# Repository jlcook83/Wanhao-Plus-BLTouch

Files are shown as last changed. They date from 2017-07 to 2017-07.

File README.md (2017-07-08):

# Wanhao-Plus-BLTouch
Wanhao i3 PLUS / Monoprice Maker Select PLUS - Marlin 1.1.3 Configured for BLTouch bed levelling probe and fully functional touch screen. 

This port is of Marlin v 1.1.3 pre-configured for use of BLTouch for bed levelling on the Wanhao i3 PLUS (with touch display) and it's various clones such as the Monoprice Maker Select Plus.

This firmware is only confirmed to provide full display functionality with the PLUS versions with touchscreen. Some configuration changes may be needed to function with previous versions that have the lcd and wheel.

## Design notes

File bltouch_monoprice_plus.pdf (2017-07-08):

## Installation of BLTouch bed levelling probe

## for

## Wanhao i3 PLUS / Monoprice Maker Select PLUS

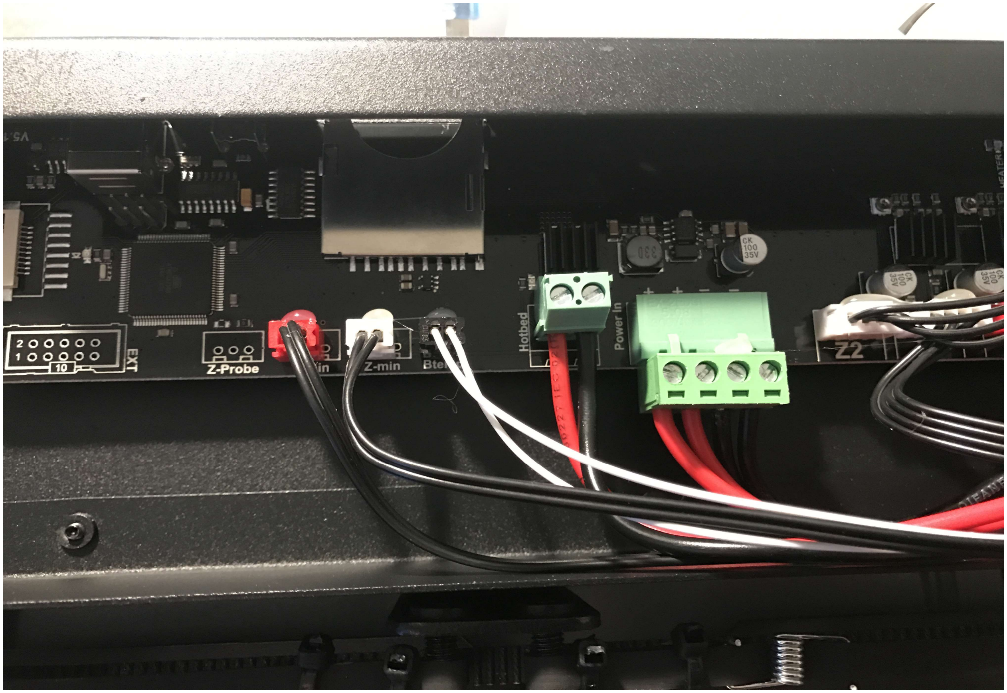
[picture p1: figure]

## 1. Disconnect Z-min connector (white)

* Z-min switch should also be lowered or removed as it will be completely replaced with the BLTouch.

2. Remove ‘0’ ohm jumper from ‘right’ solder pad, then solder jumper onto ‘left’ solder pad.
*This will supply pin 1 of Z-probe connector with 5VDC instead of 24VDC. Picture shown with jumper already moved...

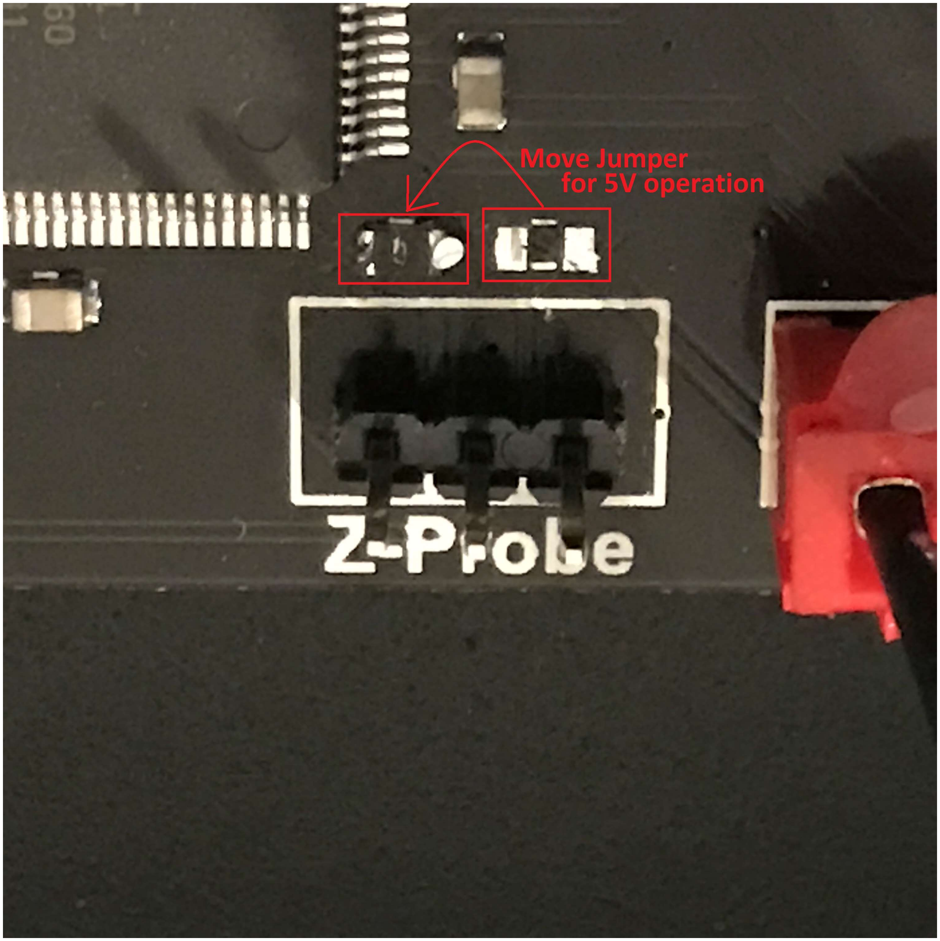
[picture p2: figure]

## 3. Wire BLTouch according to the image below –

> Note the BLTouch wire order is NOT the same as the 3-pin connector on the board, the Red and Orange wires swap positions…. > Black wire from BLTouch does not need to be connected as ground is common to the z-min and z-probe connectors...

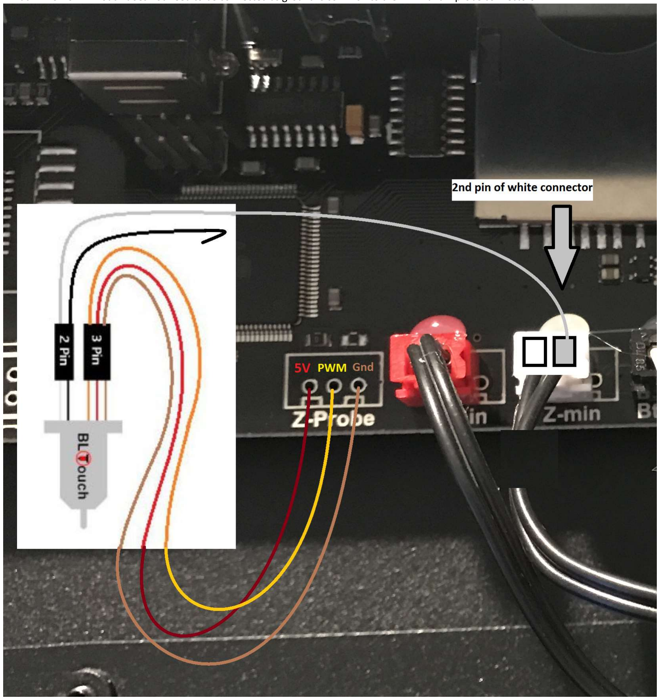
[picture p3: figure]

### 4. Mount BLTouch with an appropriate bracket…

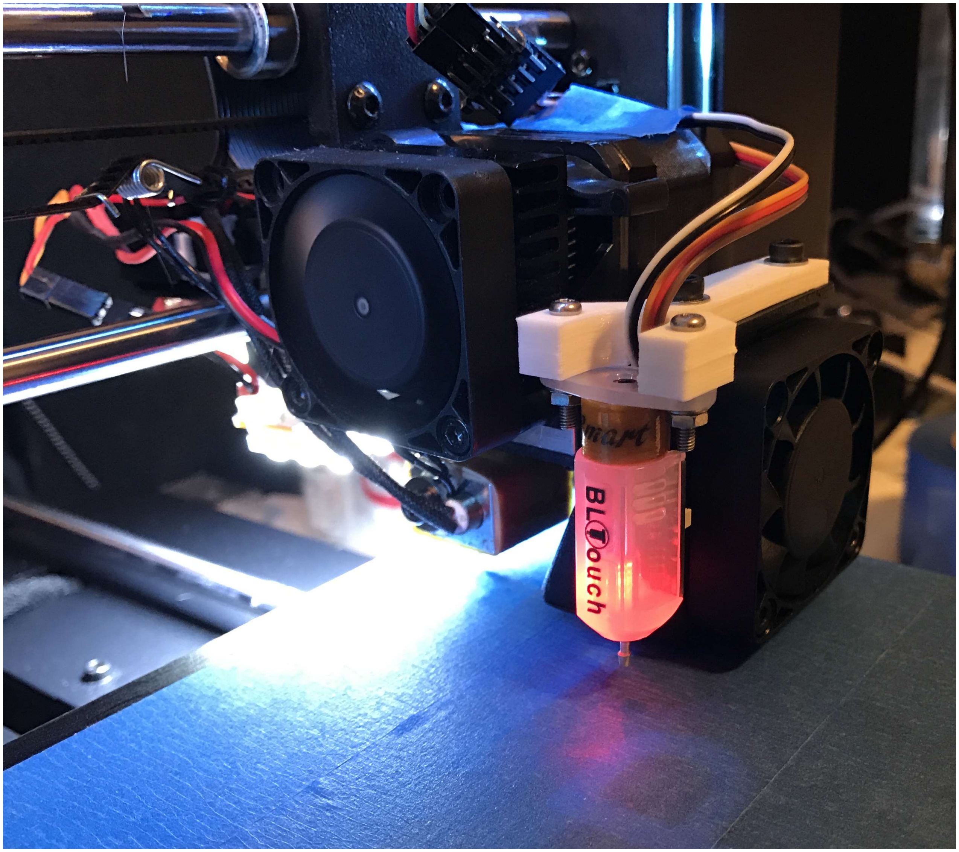
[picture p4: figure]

### 5. Install and configure firmware

- PWM Pin is ‘Arduino’ Pin #25
- Marlin software 1.1 and up has BLTouch as a bed levelling option under ‘configuration.h’

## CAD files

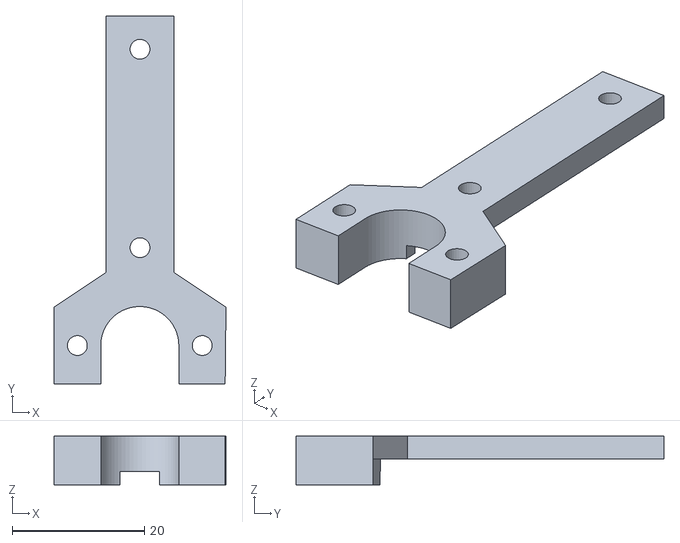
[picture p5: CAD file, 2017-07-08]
BLTouchMountV2.1_bigger.stl
26.0 x 55.6 x 7.40

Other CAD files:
BLTouch.skp

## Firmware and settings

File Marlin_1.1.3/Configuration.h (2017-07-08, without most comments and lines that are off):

#define CONFIGURATION_H
#define CONFIGURATION_H_VERSION 010100
#define STRING_CONFIG_H_AUTHOR "(none, default config)" // Who made the changes.
#define SHOW_BOOTSCREEN
#define STRING_SPLASH_LINE1 SHORT_BUILD_VERSION // will be shown during bootup in line 1
#define STRING_SPLASH_LINE2 WEBSITE_URL         // will be shown during bootup in line 2
#define SERIAL_PORT 0
#define BAUDRATE 115200
  #define MOTHERBOARD BOARD_RAMPS_13_EFB   // CLOSEST MATCH TO Monoprice Maker Select Plus - some modifications in pins_RAMPS.h
#define EXTRUDERS 1
#define POWER_SUPPLY 0  // WAS SET TO ATX '1' in old MMSP FW, but did not have the option '0' before, which is more suited for MMSP
#define TEMP_SENSOR_0 1
#define TEMP_SENSOR_1 0
#define TEMP_SENSOR_2 0
#define TEMP_SENSOR_3 0
#define TEMP_SENSOR_4 0
#define TEMP_SENSOR_BED 1 //0 ->1 MMSP
#define DUMMY_THERMISTOR_998_VALUE 25
#define DUMMY_THERMISTOR_999_VALUE 100
#define MAX_REDUNDANT_TEMP_SENSOR_DIFF 10
#define TEMP_RESIDENCY_TIME 10  // (seconds)
#define TEMP_HYSTERESIS 3       // (degC) range of +/- temperatures considered "close" to the target one
#define TEMP_WINDOW     1       // (degC) Window around target to start the residency timer x degC early.
#define TEMP_BED_RESIDENCY_TIME 10  // (seconds)
#define TEMP_BED_HYSTERESIS 3       // (degC) range of +/- temperatures considered "close" to the target one
#define TEMP_BED_WINDOW     1       // (degC) Window around target to start the residency timer x degC early.
#define HEATER_0_MINTEMP 0 //5  ->0 MMSP
#define HEATER_1_MINTEMP 5
#define HEATER_2_MINTEMP 5
#define HEATER_3_MINTEMP 5
#define HEATER_4_MINTEMP 5
#define BED_MINTEMP 0 //5  ->0 MMSP
#define HEATER_0_MAXTEMP 260 //275  ->260 MMSP
#define HEATER_1_MAXTEMP 275
#define HEATER_2_MAXTEMP 275
#define HEATER_3_MAXTEMP 275
#define HEATER_4_MAXTEMP 275
#define BED_MAXTEMP 110 //150  ->110 MMSP
#define PIDTEMP
#define BANG_MAX 255 // limits current to nozzle while in bang-bang mode; 255=full current
#define PID_MAX BANG_MAX // limits current to nozzle while PID is active (see PID_FUNCTIONAL_RANGE below); 255=full current
  #define PID_FUNCTIONAL_RANGE 10 // If the temperature difference between the target temperature and the actual temperature
  #define K1 0.95 //smoothing factor within the PID
  #define  DEFAULT_Kp 25.5 //22.2
  #define  DEFAULT_Ki 1.45 //1.08
  #define  DEFAULT_Kd 112  //114
#define MAX_BED_POWER 255 // limits duty cycle to bed; 255=full current
#define PREVENT_COLD_EXTRUSION
#define EXTRUDE_MINTEMP 170
#define PREVENT_LENGTHY_EXTRUDE
#define EXTRUDE_MAXLENGTH (X_MAX_LENGTH+Y_MAX_LENGTH) //200  ->(X_MAX_LENGTH+Y_MAX_LENGTH) FROM OLD FW
#define THERMAL_PROTECTION_HOTENDS // Enable thermal protection for all extruders
#define THERMAL_PROTECTION_BED     // Enable thermal protection for the heated bed
#define USE_XMIN_PLUG
#define USE_YMIN_PLUG
#define USE_ZMIN_PLUG
  #define ENDSTOPPULLUP_XMIN  // USED FOR X SWITCH ON MMSP
  #define ENDSTOPPULLUP_YMIN  // USED FOR Y SWITCH ON MMSP
#define X_MIN_ENDSTOP_INVERTING true //false // set to true to invert the logic of the endstop.
#define Y_MIN_ENDSTOP_INVERTING true //false // set to true to invert the logic of the endstop.
#define Z_MIN_ENDSTOP_INVERTING false // set to true to invert the logic of the endstop.
#define X_MAX_ENDSTOP_INVERTING false // set to true to invert the logic of the endstop.
#define Y_MAX_ENDSTOP_INVERTING false // set to true to invert the logic of the endstop.
#define Z_MAX_ENDSTOP_INVERTING false // set to true to invert the logic of the endstop.
#define Z_MIN_PROBE_ENDSTOP_INVERTING false // set to true to invert the logic of the probe.
#define DEFAULT_AXIS_STEPS_PER_UNIT   { 80, 80, 400, 99 }
#define DEFAULT_MAX_FEEDRATE          { 450, 450, 5, 25 }  //{ 300, 300, 5, 25 } //MMSP
#define DEFAULT_MAX_ACCELERATION      { 3000, 3000, 100, 3000 } // {400,400,100,3000}  //MMSP
#define DEFAULT_ACCELERATION          800 //3000    // X, Y, Z and E acceleration for printing moves
#define DEFAULT_RETRACT_ACCELERATION  800 //3000    // E acceleration for retracts
#define DEFAULT_TRAVEL_ACCELERATION   800 //3000    // X, Y, Z acceleration for travel (non printing) moves
#define DEFAULT_XJERK                 10.0 //20.0
#define DEFAULT_YJERK                 10.0 //20.0
#define DEFAULT_ZJERK                 0.4
#define DEFAULT_EJERK                 1.0 // 5.0
#define Z_MIN_PROBE_USES_Z_MIN_ENDSTOP_PIN
#define BLTOUCH
  #define BLTOUCH_DELAY 375   // (ms) Enable and increase if needed
#define X_PROBE_OFFSET_FROM_EXTRUDER -21 //10  // X offset: -left  +right  [of the nozzle]
#define Y_PROBE_OFFSET_FROM_EXTRUDER -46 //10  // Y offset: -front +behind [the nozzle]
#define Z_PROBE_OFFSET_FROM_EXTRUDER -1.5 //0   // Z offset: -below +above  [the nozzle]
#define XY_PROBE_SPEED 8000
#define Z_PROBE_SPEED_FAST (HOMING_FEEDRATE_Z)
#define Z_PROBE_SPEED_SLOW (Z_PROBE_SPEED_FAST / 3.0)
#define PROBE_DOUBLE_TOUCH
#define Z_CLEARANCE_DEPLOY_PROBE   3// Z Clearance for Deploy/Stow
#define Z_CLEARANCE_BETWEEN_PROBES  5 // Z Clearance between probe points
#define Z_PROBE_OFFSET_RANGE_MIN -20
#define Z_PROBE_OFFSET_RANGE_MAX 20
#define Z_MIN_PROBE_REPEATABILITY_TEST
#define X_ENABLE_ON 0
#define Y_ENABLE_ON 0
#define Z_ENABLE_ON 0
#define E_ENABLE_ON 0 // For all extruders
#define DISABLE_X false
#define DISABLE_Y false
#define DISABLE_Z false
#define DISABLE_E false // For all extruders
#define DISABLE_INACTIVE_EXTRUDER true // Keep only the active extruder enabled.
#define INVERT_X_DIR true //false
#define INVERT_Y_DIR true
#define INVERT_Z_DIR false
#define INVERT_E0_DIR false
#define INVERT_E1_DIR false
#define INVERT_E2_DIR false
#define INVERT_E3_DIR false
#define INVERT_E4_DIR false
#define Z_HOMING_HEIGHT 5  // (in mm) Minimal z height before homing (G28) for Z clearance above the bed, clamps, ...
#define X_HOME_DIR -1
#define Y_HOME_DIR -1
#define Z_HOME_DIR -1
#define X_MIN_POS 0
#define Y_MIN_POS 0
#define Z_MIN_POS 0
#define X_MAX_POS 200
#define Y_MAX_POS 206
#define Z_MAX_POS 180
#define MIN_SOFTWARE_ENDSTOPS
#define MAX_SOFTWARE_ENDSTOPS
#define AUTO_BED_LEVELING_BILINEAR
  #define ENABLE_LEVELING_FADE_HEIGHT
  #define GRID_MAX_POINTS_X 3
  #define GRID_MAX_POINTS_Y GRID_MAX_POINTS_X
  #define LEFT_PROBE_BED_POSITION 20
  #define RIGHT_PROBE_BED_POSITION 169
  #define FRONT_PROBE_BED_POSITION 20
  #define BACK_PROBE_BED_POSITION 160
  #define MIN_PROBE_EDGE 10
#define Z_SAFE_HOMING
  #define Z_SAFE_HOMING_X_POINT ((X_MIN_POS + X_MAX_POS) / 2)    // X point for Z homing when homing all axis (G28).
  #define Z_SAFE_HOMING_Y_POINT ((Y_MIN_POS + Y_MAX_POS) / 2)    // Y point for Z homing when homing all axis (G28).
#define HOMING_FEEDRATE_XY (50*60)
#define HOMING_FEEDRATE_Z  (4*60)
#define EEPROM_SETTINGS
  #define EEPROM_CHITCHAT // Please keep turned on if you can.
#define HOST_KEEPALIVE_FEATURE        // Disable this if your host doesn't like keepalive messages
#define DEFAULT_KEEPALIVE_INTERVAL 2  // Number of seconds between "busy" messages. Set with M113.
#define PREHEAT_1_TEMP_HOTEND 200 //180
#define PREHEAT_1_TEMP_BED     60 //70
#define PREHEAT_1_FAN_SPEED     0 // Value from 0 to 255
#define PREHEAT_2_TEMP_HOTEND 240
#define PREHEAT_2_TEMP_BED    110
#define PREHEAT_2_FAN_SPEED     0 // Value from 0 to 255
#define NOZZLE_PARK_FEATURE
  #define NOZZLE_PARK_POINT { (X_MIN_POS + 10), (Y_MAX_POS - 10), 20 }
#define NOZZLE_CLEAN_FEATURE
  #define NOZZLE_CLEAN_STROKES  12
  #define NOZZLE_CLEAN_TRIANGLES  3
  #define NOZZLE_CLEAN_START_POINT { 30, 30, (Z_MIN_POS + 1)}
  #define NOZZLE_CLEAN_END_POINT   {100, 60, (Z_MIN_POS + 1)}
  #define NOZZLE_CLEAN_CIRCLE_RADIUS 6.5
  #define NOZZLE_CLEAN_CIRCLE_FN 10
  #define NOZZLE_CLEAN_CIRCLE_MIDDLE NOZZLE_CLEAN_START_POINT
  #define NOZZLE_CLEAN_GOBACK
#define PRINTJOB_TIMER_AUTOSTART
#define LCD_LANGUAGE en
#define DISPLAY_CHARSET_HD44780 JAPANESE
#define ULTRA_LCD   // Character based
#define SDSUPPORT
#define SD_CHECK_AND_RETRY
#define SOFT_PWM_SCALE 0
#define NUM_SERVOS 1 //3 // Servo index starts with 0 for M280 command
#define SERVO_DELAY 375
#define DEFAULT_NOMINAL_FILAMENT_DIA 1.75 //3.00   // (mm) Diameter of the filament generally used (3.0 or 1.75mm), also used in the slicer. Used to validate sensor reading.

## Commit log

2017-07-08 stl model of custom BLTouch bracket
    [BLTouchMountV2.1_bigger.stl]
2017-07-21 sketchup file
    bracket could be extended just slightly more so that sensor wire connector doesn't touch fan shroud...
    [BLTouch.skp]
2018-01-12 Monoprice HMI-Display Original Files
    Original HMI-Display SD card files. A few bmp files were edited so that "sava" now reads correctly as "save".
    [CONFIG.txt]

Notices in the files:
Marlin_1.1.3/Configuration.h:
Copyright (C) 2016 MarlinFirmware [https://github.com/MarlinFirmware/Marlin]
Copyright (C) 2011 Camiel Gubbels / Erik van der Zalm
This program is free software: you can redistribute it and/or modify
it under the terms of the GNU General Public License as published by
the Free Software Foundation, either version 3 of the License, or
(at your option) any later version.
